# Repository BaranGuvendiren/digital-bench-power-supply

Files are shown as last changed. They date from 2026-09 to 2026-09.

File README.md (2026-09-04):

# digital-bench-power-supply

## Disclaimer & Project Status
I started this project as a 2nd-year Electronics Engineering student to learn power electronics and PCB design in practice.  

While university courses mostly provided hypothetical ideal circuits, this project forced me to confront real-world effects on circuits (e.g., parasitic inductance, ESR, switching noise).

- **No Warranty:** This is **not** a consumer-grade product. While I tried to follow standard engineering practices, it has not undergone any formal testing (such as EMC).

***Current Status:*** *On-going*

***Documentation Notes***:  
- *Currently specified values (voltages, currents, frequencies) are initial design targets and may be optimized later based on future simulations and hardware testing.*
- *Detailed mathematical calculations, circuit schematics and simulation results are currently being formatted and will be documented in their respective sections soon.*

## Features
### Connections & Power
- Powered by a standard laptop adapter (19–20 V, ≥ 65 W) (2.5 mm DC Barrel Jack).
- Includes a USB-C port and SWD pins for PC connection and debugging.
### Protection & Safety
- Reverse polarity protection via P-MOSFET.
- Soft start via P-MOSFET, integrated with a mechanical switch on the gate for system ON/OFF control.
- Temperature-controlled fan.
- NPN-based active current sink at the output rail to maintain LDO stability under zero-load or light-load conditions.
### Output
- Digitally adjustable output (1.2–14 V, up to 2.75 A).
- LDO output with buck controller as a pre-regulator.
- Multi-stage filtering.
- OLED display module.

*Note: A third-party display module is used to prevent the project scope from becoming excessively broad.*

## Design Goals
- Portable design.
- Low-noise output.

## Hardware Architecture Overview
This section provides a simplified blueprint of the system architecture, focusing on the core operating principles and critical design blocks without getting into mathematical formulas or component details.

```mermaid
flowchart LR
  subgraph INPUT_STAGE [Input & Protection]
    IN[Power Adapter] --> PROT[Reverse Prot] --> PI1[Pi-filter]
  end

  subgraph MAIN_RAIL [Main Power Rail]
    PI1 --> BUCK_ADJ[Adjustable Buck]
    BUCK_ADJ --> PI2[Pi-filter] --> SHUNT[Shunt Resistor] --> LDO_ADJ[Adjustable LDO] --> OUT((LOAD))
  end

  subgraph AUX_RAILS [Auxiliary Rails]
    PI1 --> BUCK_5V[5V Buck]
    PI1 --> BUCK_12V[12V Buck]
    BUCK_5V --> PI3[Pi-filter] --> LDO_3V3_D[3V3 Digital]
    BUCK_5V --> PI4[Pi-filter] --> LDO_3V3_A[3V3 Analog]
  end

  subgraph CONTROL [Control & Feedback]
    MCU[MCU]
    AMP[Current Amp]
    DISP[OLED]
    FAN[Fan]
  end

  LDO_3V3_D --> MCU
  LDO_3V3_A --> AMP
  BUCK_5V --> DISP
  BUCK_12V --> FAN

  MCU -.->|V-Set| LDO_ADJ
  MCU -.->|I-Limit| BUCK_ADJ
  MCU -.->|PWM| FAN
  MCU -.->|SPI| DISP
    
  SHUNT -.-> AMP
  AMP -.-> MCU
    
  LDO_ADJ -.->|Pre-reg FB| BUCK_ADJ
```

### Stage 1: Power Input & Input Filtering
* **Input Pre-Filtering:** To prevent beat frequency interference and cross-rail noise coupling, a common CLC Pi-filter is placed immediately after the input.
  
* **Switching Frequency Planning:** To prevent similar interference across rails, operating frequencies are explicitly separated:
    - Laptop Adapter: ~100 kHz
    - Main Buck Regulator: 435 kHz
    - Auxiliary 12 V Buck Regulator: 570 kHz
    - Auxiliary 5 V Buck Regulator: 1 MHz

*Note: Other than common power input, both power rails ("Stage 2A" and "Stage 2B") are independent from each other.*

### Stage 2A: Main Adjustable Power Rail (Buck Converter & LDO)
* **Pre-Regulation:** To achieve stable and low-noise output, an LDO is used. However, since possible high output current may cause an impractical amount of power dissipation, a buck pre-regulator is implemented to maintain a minimal and constant dropout voltage.

* **CC & CV Modes:** While the Constant Current (CC) and Constant Voltage (CV) limits are digitally set by the MCU, relying solely on software poses a reliability risk in high-noise power environments. Therefore, a hardware resistor network restricts the maximum voltage the feedback circuit can receive, preventing both V-set and I-limit signals from exceeding safe operational thresholds.
  
* **Current and Voltage Sensing:** The output current is measured using a shunt resistor paired with a current sense amplifier. The output voltage is sampled via a dedicated voltage divider connected to the LDO output rail. Both analog signals are then processed by the MCU's ADC and displayed on the OLED screen.

### Stage 2B: Auxiliary Power Rails (12 V Buck & 5 V Buck & 3.3 V LDOs)
* **Two-Level Regulation & Noise Isolation:** A 5 V Buck regulator serves as a pre-regulator for the 3.3 V LDOs, while directly powering the fan and the external display. To achieve clean signal processing, separate LDOs are dedicated to the analog and digital rails. This isolation prevents high-frequency digital switching noise from coupling into the sensitive analog rail. Additionally, both LDO lines include a ferrite bead Pi-filter at their inputs to block high-frequency EMI noise that LDOs struggle to suppress.

* **Temperature-Controlled PWM Fan:** To optimize thermal management and minimize both acoustic and electrical noise, the cooling fan operates only when required. The MCU monitors the system temperature and drives an N-MOSFET via PWM to dynamically adjust the fan speed proportional to the device temperature.

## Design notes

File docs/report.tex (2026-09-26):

\documentclass[11pt, a4paper]{article}
\usepackage[top=2.5cm, bottom=2.5cm, left=2cm, right=2cm]{geometry}

\input{variables.tex}

\usepackage[T1]{fontenc}
\usepackage{lmodern}
% \usepackage{helvet}
% \renewcommand{\familydefault}{\sfdefault}
\setlength{\parindent}{0pt}

\usepackage{amsmath, amssymb}
\usepackage{siunitx}
\sisetup{
    scientific-notation = engineering,
    output-decimal-marker = {.},
    drop-zero-decimal = true,
    exponent-to-prefix = true,
    exponent-product = \cdot,
    round-mode = places,
    round-precision = 2,
    per-mode = symbol
}

\usepackage{caption}
\captionsetup[table]{skip=2pt}

\usepackage[colorlinks=true, linkcolor=black, urlcolor=black, citecolor=black]{hyperref}
\usepackage{graphicx}
\graphicspath{{images/}}
\usepackage{fancyhdr}
\pagestyle{fancy}
\fancyhf{}
\fancyhead[L]{\small REVISED \today}
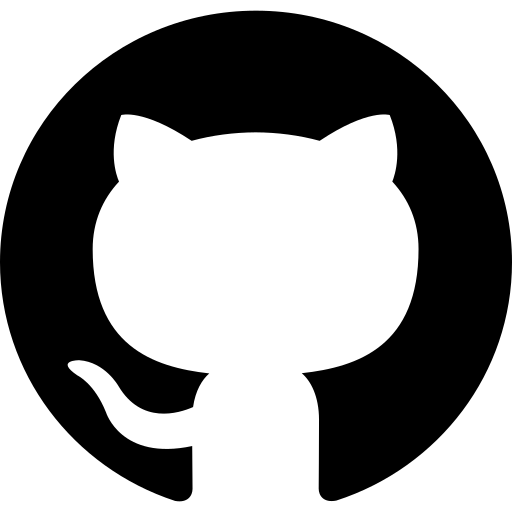
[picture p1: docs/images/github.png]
\fancyhead[R]{\small\raisebox{-0.4ex}{} {\href{https://github.com/BaranGuvendiren/digital-bench-power-supply}{\texttt{GitHub Repository}}}}
\fancyfoot[C]{\thepage}

\usepackage{tabularx}
\usepackage{multirow}
\usepackage[table]{xcolor}
\renewcommand{\arraystretch}{1.4}

\usepackage[most]{tcolorbox}
\newtcolorbox{pickedbox}{
  enhanced,
  blanker,
  borderline west={1pt}{0pt}{gray!50},
  left=10pt, top=4pt, bottom=4pt
}

\usepackage{multicol}
\usepackage{tocloft}
\renewcommand{\cftsecfont}{\small\bfseries\sffamily}
\renewcommand{\cftsecpagefont}{\small\sffamily\color{blue}}
\renewcommand{\cftsubsecfont}{\small\sffamily}
\renewcommand{\cftsubsecpagefont}{\small\sffamily\color{blue}}
\renewcommand{\contentsname}{}
\renewcommand{\cftdotsep}{0.2}
\renewcommand{\cftsecleader}{\cftdotfill{\cftdotsep}}

\setlength{\cftbeforesecskip}{2pt}
\setlength{\cftbeforesubsecskip}{0pt}
\begin{document}

% Title Page
\begin{titlepage}
    \centering
    \vspace*{1.5cm}
    {\scshape\Large Hardware Design \& Verification Report \par}
    \vspace{2.5cm}
    
    {\huge\bfseries Digital Bench Power Supply \par}
    \vspace{0.4cm}
    
    {\Large\itshape Design Calculations, Circuit Simulations \& Hardware Verification \par}
    \rule{\textwidth}{1.2pt}
    
    \vspace{2.5cm}
    
    {\large\bfseries Baran Güvendiren \par}
    \vspace{0.2cm}
    {\small Electronics Engineering Student \par}

    \vfill
    \begin{minipage}{0.85\textwidth}
        \centering
        \small\itshape
        This document contains the complete theoretical calculations, simulation models, component selection justification and hardware verifications for the project.
    \end{minipage}
\end{titlepage}
\clearpage

% Table of Contents
\hypersetup{linkcolor=blue, linktoc=page}

{\centering\Large\bfseries\sffamily Table of Contents \par}
\vspace{0.25cm}

\begin{multicols}{2}
  \setcounter{tocdepth}{2}
  \tableofcontents
  \thispagestyle{fancy}
\end{multicols}
\rule{\textwidth}{0.4pt}

\hypersetup{linkcolor=black}
\clearpage

\section{Calculations \& Component Selection}
\subsection{Overview}
This section contains the theoretical calculations and engineering decisions used to determine the component values for each stage of the power supply. \\[0.5em]
The datasheet files containing manufacturer specifications and references used in these calculations are located in the \small\href{https://github.com/BaranGuvendiren/digital-bench-power-supply/tree/main/docs/datasheets}{\texttt{docs/datasheet/}} directory of the project repository. \\[1em]
{\small\itshape Note: Some calculations are based on idealized formulas with sufficient design margin to ensure system stability and flexibility in component selection. \par}

\normalsize
\subsection{Naming Convention \& Notations}
To maintain mathematical clarity across multiple stages, variables are named using the following conventions:
\begin{table}[h]
\centering
\caption{Naming Convention}
\label{tab:convention}
\small
\begin{tabularx}{\textwidth}{|l|>{\raggedright\arraybackslash}X|l|}
\hline
\rowcolor{gray!20} 
\textbf{Notation Format} & \textbf{Description}               & \textbf{Example} \\ \hline
No Parentheses           & Global board-level variable        & $\mathrm{V_{OUT}}$ (Board output voltage) \\ \hline
With Parentheses         & Component specific to a certain IC & $\mathrm{V_{OUT(U1)}}$ (Output voltage specific to U1 - LM25117) \\ \hline
\end{tabularx}
\end{table}

{\small\itshape Note: The number inside the parentheses indicates which integrated circuit (IC) the variable belongs to. \par}

\begin{table}[h]
\centering
\caption{IC Reference Table}
\label{tab:notations}
\small
\begin{tabularx}{\textwidth}{|c|c|>{\raggedright\arraybackslash}X|}
\hline
\rowcolor{gray!20} 
\textbf{IC Number} & \textbf{Component Name} & \textbf{Description} \\ \hline
1                  & LM25117                 & Main Buck Pre-Regulator \\ \hline
2                  & MIC29302                & Main LDO \\ \hline
4                  & TPS54331                & Auxiliary 5 V Buck Regulator \\ \hline
6                  & TPS54332                & Auxiliary 12 V Buck Regulator \\ \hline
\end{tabularx}
\end{table}

\subsection{LM25117 - U1}
\subsubsection{Timer Resistor \texorpdfstring{$\mathrm{R_{T(U1)}}$}{RT(U1)}}
The switching frequency of the main buck regulator was set to \qty{\fswA}{\hertz} via the $\mathrm{R_{T(U1)}}$ pin resistor; 
this enables sufficient separation from the adapter's lower switching frequency ($\approx \qty{100e3}{\hertz}$) to minimize beat frequency noise, while preventing excessive switching losses at higher frequencies.
\begin{align}
\mathrm{R_{T(U1)}} &= \frac{\num{5.2e9}}{\mathrm{f_{SW(U1)}}} - 949 \nonumber \\[0.5em]
                   &= \frac{\num{5.2e9}}{\num{\fswA}} - 949 \approx \qty{\CalcRtA}{\ohm}
\end{align}
\begin{pickedbox}
\small\textbf{Picked Value(s):}\\[0.5em]
$\diamond\quad \mathrm{R_{T(U1)}} = \qty{\RtA}{\ohm}$
\end{pickedbox}

\subsubsection{Output Inductor \texorpdfstring{$\mathrm{L_{O(U1)}}$}{LO(U1)}}
The output inductance was calculated using a nominal mid-range voltage of $\mathrm{V_{OUT(TYP)}} = \qty{\VoutTyp}{\volt}$ to achieve a balanced ripple current trade-off over the full output voltage range. 
In addition, maximum inductor ripple ($\mathrm{I_{PP(U1)}}$) current was selected as \qty{20}{\percent} of the full load current.
\begin{align}
\mathrm{L_{O(U1)}} &= \frac{\mathrm{V_{OUT(TYP)}}}{\mathrm{I_{PP(U1)}} \cdot \mathrm{f_{SW(U1)}}} \cdot \left(1 - \frac{\mathrm{V_{OUT(TYP)}}}{\mathrm{V_{IN}}}\right) \nonumber  \\[0.5em]
                   &= \frac{\VoutTyp}{\IppA \cdot \num{\fswA}} \cdot \left(1 - \frac{\VoutTyp}{\Vin}\right) \approx \qty{\CalcLoA}{\henry}
\end{align}
\begin{pickedbox}
\small\textbf{Picked Value(s):}\\[0.5em]
$\diamond\quad \mathrm{L_{O(U1)}} = \qty{\LoA}{\henry}$
\end{pickedbox}

\subsubsection{Current Sense Resistor \texorpdfstring{$\mathrm{R_{CS(U1)}}$}{RCS(U1)}}
Maximum output current capability ($\mathrm{I_{OUT(MAX)}}$) was selected as \qty{150}{\percent} of the full load current to account for tolerances. \\[1em]
{\small\itshape Note: Since the LM25117 uses an emulated current ramp, it reads the valley current just before the high-side switch turns on. This means the controller is unaffected by the large leading-edge switching spikes. 
Therefore, a current sense filter was not used in this design to avoid propagation delay on current sensing. \par}
\begin{align}
\mathrm{R_{CS(U1)}}  &= \frac{\mathrm{V_{CS(TH)}}}{\mathrm{I_{OUT(MAX)}} + \dfrac{\mathrm{V_{OUT(TYP)}} \cdot \mathrm{K}}{\mathrm{f_{SW(U1)}} \cdot \mathrm{L_{O(U1)}}} - \dfrac{\mathrm{I_{PP(U1)}}}{2}} \nonumber \\[0.5em]
                     &= \frac{0.12}{\num{\IoutMax} + \dfrac{\num{\VoutTyp} \cdot 1}{\num{\fswA} \cdot \num{\LoA}} - \dfrac{\num{\IppA}}{2}} \approx \qty{\CalcRcsA}{\ohm}\\[1.5em]
\mathrm{P_{RCS(U1)}} &= \left(1 - \frac{\mathrm{V_{OUT(MIN)(U1)}}}{\mathrm{V_{IN}}}\right) \cdot \mathrm{I_{OUT}}^2 \cdot \mathrm{R_{CS(U1)}} \nonumber \\[0.5em]
                     &= \left(1 - \frac{\num{\VoutMin}}{\num{\Vin}}\right) \cdot \num{\Iout}^2 \cdot \num{\RcsA} \approx \qty{\PrcsA}{\watt}
\end{align}
\begin{pickedbox}
\small\textbf{Picked Value(s):}\\[0.5em]
$\diamond\quad \mathrm{R_{CS(U1)}} = \qty{\RcsA}{\ohm}$ \\[0.25em]
$\diamond\quad \mathrm{P_{RCS(U1)}} = \text{[TBD]}$  % \qty{\Prcs}{\watt}
\end{pickedbox}

\subsubsection{Ramp Resistor and Capacitor \texorpdfstring{$\mathrm{R_{RAMP(U1)}}$ and $\mathrm{C_{RAMP(U1)}}$}{CRAMP(U1)}}
Current sense amplifier gain ($\mathrm{A_{RAMP}}$) and K factor are both defined in the datasheet. K factor was set to 1 to prevent sub-harmonic oscillations and ensure one-cycle damping, as recommended in the datasheet. \\[1em]
{\small\itshape Note: The value of $\mathrm{C_{RAMP(U1)}}$ was set to the standard capacitor value of 1 nF. \par}
\begin{align}
\mathrm{R_{RAMP(U1)}} &= \frac{\mathrm{L_{O(U1)}}}{\mathrm{K} \cdot \mathrm{C_{RAMP(U1)}} \cdot \mathrm{R_{CS(U1)}} \cdot \mathrm{A_{RAMP}}} \nonumber \\[0.5em]
                      &= \frac{\num{\LoA}}{1 \cdot \num{\CrampA} \cdot \num{\RcsA} \cdot 10} = \qty{\CalcRrampA}{\ohm}
\end{align}
\begin{pickedbox}
\small\textbf{Picked Value(s):}\\[0.5em]
$\diamond\quad \mathrm{R_{RAMP(U1)}} = \qty{\RrampA}{\ohm}$ \\[0.25em]
$\diamond\quad \mathrm{C_{RAMP(U1)}} = \qty{\CrampA}{\farad}$
\end{pickedbox}

\subsubsection{Output Shunt Resistor \texorpdfstring{$\mathrm{R_S}$}{RS}}
The output current was measured by converting the load current ($\mathrm{I_{OUT(U1)}}$) into an analog voltage signal via a dedicated shunt resistor and a current sense amplifier. The resulting analog signal was then digitized by the MCU's ADC. 
Since the LDO's input current is approximately equal to its output current, the shunt resistor was placed before the feedback node at the LDO input to prevent the voltage drop across the shunt resistor from affecting the regulated output voltage. \\[0.5em]
As low power consumption was not a primary concern for this project, the amplifier gain ($\mathrm{A_S}$) was set to \qty{50}{\times} to minimize the amplification of measurement errors. 
In addition, the reference voltage ($\mathrm{V_{S(REF)}}$) was limited to \qty{3}{\volt}, providing \qty{0.3}{\volt} headroom below the MCU supply voltage to reduce the impact of possible control errors. \\[1em]
{\small\itshape Note: $R_{CS(U1)}$ was used to measure the inductor valley current for LM25117's emulated current-mode control, while $R_S$ was used to calculate the output current for monitoring and setting CC-mode current limit. \par}
\begin{align}
\mathrm{R_S}    &= \frac{\mathrm{V_{S(REF)}} / \mathrm{A_S}}{\mathrm{I_{OUT}}} \nonumber \\[0.5em] 
                &= \frac{\TargVsRef / \As}{\Iout} \approx \qty{\CalcRs}{\ohm} \\[1.5em]
\mathrm{P_{RS}} &= \mathrm{I_{OUT}}^2 \cdot \mathrm{R_S} \nonumber \\[0.5em]
                &= \num{\Iout}^2 \cdot \num{\Rs} \approx \qty{\CalcPrs}{\watt}
\end{align}
\begin{pickedbox}
\small\textbf{Picked Value(s):}\\[0.5em]
$\diamond\quad \mathrm{R_S} = \qty{\Rs}{\ohm}$ \\[0.25em]
$\diamond\quad \mathrm{P_{RS}} = \text{[TBD]}$  % \qty{\Prs}{\watt}
\end{pickedbox}
\end{document}

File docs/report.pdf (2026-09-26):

Hardware Design & Verification Report

# Digital Bench Power Supply

### Design Calculations, Circuit Simulations & Hardware Verification

Baran Güvendiren

Electronics Engineering Student

This document contains the complete theoretical calculations, simulation models, component selection justification and hardware verifications for the project.

REVISED September 26, 2026 | GitHub Repository (https://github.com/BaranGuvendiren/digital-bench-power-supply)

### Table of Contents

### 1 Calculations & Component Selection

### 1.1 Overview

This section contains the theoretical calculations and engineering decisions used to determine the component values for each stage of the power supply.
The datasheet files containing manufacturer specifications and references used in these calculations are located in the docs/datasheet/ (https://github.com/BaranGuvendiren/digital-bench-power-supply/tree/main/docs/datasheets) directory of the project repository.

Note: Some calculations are based on idealized formulas with sufficient design margin to ensure system stability and flexibility in component selection.

### 1.2 Naming Convention & Notations

To maintain mathematical clarity across multiple stages, variables are named using the following conventions:

Table 1: Naming Convention

Notation Format | Description | Example
No Parentheses | Global board-level variable | VOUT (Board output voltage)
With Parentheses | Component specific to a certain IC | VOUT(U1) (Output voltage specific to U1 - LM25117)

Note: The number inside the parentheses indicates which integrated circuit (IC) the variable belongs to.

Table 2: IC Reference Table

IC Number | Component Name | Description
1 | LM25117 | Main Buck Pre-Regulator
2 | MIC29302 | Main LDO
4 | TPS54331 | Auxiliary 5 V Buck Regulator
6 | TPS54332 | Auxiliary 12 V Buck Regulator

### 1.3 LM25117 - U1

### 1.3.1 Timer Resistor RT(U1)

The switching frequency of the main buck regulator was set to 435 kHz via the RT(U1) pin resistor; this enables sufficient separation from the adapter’s lower switching frequency (≈ 100 kHz) to minimize beat frequency noise, while preventing excessive switching losses at higher frequencies.

RT(U1) =

5.20 · 10⁹

fSW(U1)

− 949

=

5.20 · 10⁹
435 · 10³
− 949 ≈ 11.01 kΩ | (1)

Picked Value(s):

⋄ RT(U1) = 11 kΩ

### 1.3.2 Output Inductor LO(U1)

The output inductance was calculated using a nominal mid-range voltage of VOUT(TYP) = 8 V to achieve a balanced ripple current trade-off over the full output voltage range. In addition, maximum inductor ripple (IPP(U1)) current was selected as 20 % of the full load current.

LO(U1) =

VOUT(TYP)

IPP(U1) · fSW(U1)

·

1 −

VOUT(TYP)

VIN

=

8.0
0.55 · 435 · 10³

·

1 −

8.0
20.0
≈ 20.06 µH | (2)

Picked Value(s):

⋄ LO(U1) = 20 µH

### 1.3.3 Current Sense Resistor RCS(U1)

Maximum output current capability (IOUT(MAX)) was selected as 150 % of the full load current to account for tolerances.

Note: Since the LM25117 uses an emulated current ramp, it reads the valley current just before the high-side switch turns on. This means the controller is unaffected by the large leading-edge switching spikes. Therefore, a current sense filter was not used in this design to avoid propagation delay on current sensing.

RCS(U1) =

VCS(TH)

IOUT(MAX) +

VOUT(TYP) · K

fSW(U1) · LO(U1)

−

IPP(U1)
2

=

0.12

4.13 +

8 · 1
435 · 10³ · 20 · 10⁻⁶

−

550 · 10⁻³
2
≈ 25.16 mΩ | (3)

PRCS(U1) =

1 −

VOUT(MIN)(U1)

VIN

- IOUT

2
- RCS(U1)

=

1 −

1.25
20
- 2.75²
- 25 · 10⁻³ ≈ 177.59 mW | (4)

Picked Value(s):

⋄ RCS(U1) = 25 mΩ
⋄ PRCS(U1) = [TBD]

### 1.3.4 Ramp Resistor and Capacitor RRAMP(U1) and CRAMP(U1)

Current sense amplifier gain (ARAMP) and K factor are both defined in the datasheet. K factor was set to 1 to prevent sub-harmonic oscillations and ensure one-cycle damping, as recommended in the datasheet.

Note: The value of CRAMP(U1) was set to the standard capacitor value of 1 nF.

RRAMP(U1) =

LO(U1)

K · CRAMP(U1) · RCS(U1) · ARAMP

=

20 · 10⁻⁶
1 · 1 · 10⁻⁹ · 25 · 10⁻³ · 10
= 80 kΩ | (5)

Picked Value(s):

⋄ RRAMP(U1) = 80 kΩ
⋄ CRAMP(U1) = 1 nF

### 1.3.5 Output Shunt Resistor RS

The output current was measured by converting the load current (IOUT(U1)) into an analog voltage signal via a dedicated shunt resistor and a current sense amplifier. The resulting analog signal was then digitized by the MCU’s ADC. Since the LDO’s input current is approximately equal to its output current, the shunt resistor was placed before the feedback node at the LDO input to prevent the voltage drop across the shunt resistor from affecting the regulated output voltage.
As low power consumption was not a primary concern for this project, the amplifier gain (AS) was set to 50 × to minimize the amplification of measurement errors. In addition, the reference voltage (VS(REF)) was limited to 3 V, providing 300 mV headroom below the MCU supply voltage to reduce the impact of possible control errors.

Note: RCS(U1) was used to measure the inductor valley current for LM25117’s emulated current-mode control, while RS was used to calculate the output current for monitoring and setting CC-mode current limit.

RS =

VS(REF)/AS

IOUT

=

3.0/50
2.75
≈ 21.82 mΩ | (6)

PRS = IOUT

2
- RS

= 2.75²

- 22 · 10⁻³ ≈ 166.38 mW | (7)

Picked Value(s):

⋄ RS = 22 mΩ
⋄ PRS = [TBD]

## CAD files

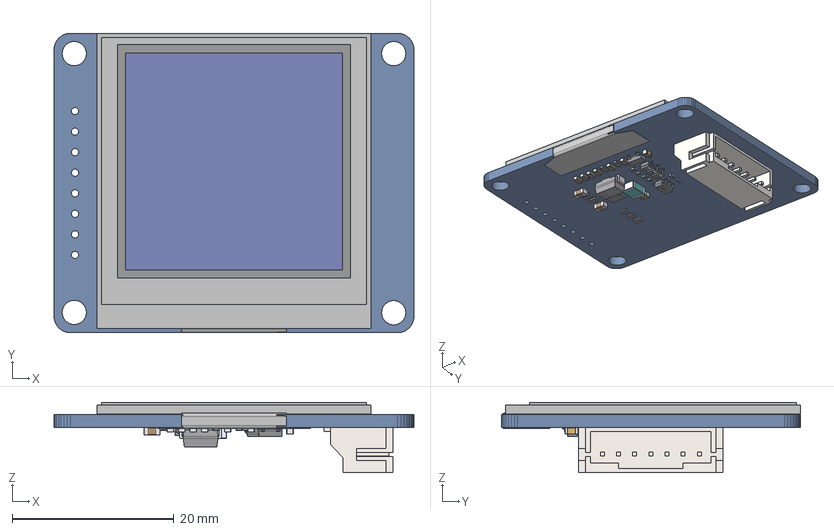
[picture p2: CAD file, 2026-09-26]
enclosure/3d-models/OLED-module.stp
44.5 x 37.0 x 8.70 mm
BOARD
RESC1608_0603_ x 7
SW3DPS-3-LEAD_SOT23-3
USER_LIBRARY-TSOT-23-6_S6_
SW3DPS-DO-214AC_SMA
CAPC2012_0805_ x 2
CAPC1608_0603_ x 6
INDC3225_1210_
SOD323 x 3
5_1_2_A x 7
_7_AF0 x 7
SOT23-5AND6__100 x 6
SOT23-6-7933_AF0
3_1_2_A x 2
1_5INCH-128X128-QLED
HP2_0-7PIN-SMT

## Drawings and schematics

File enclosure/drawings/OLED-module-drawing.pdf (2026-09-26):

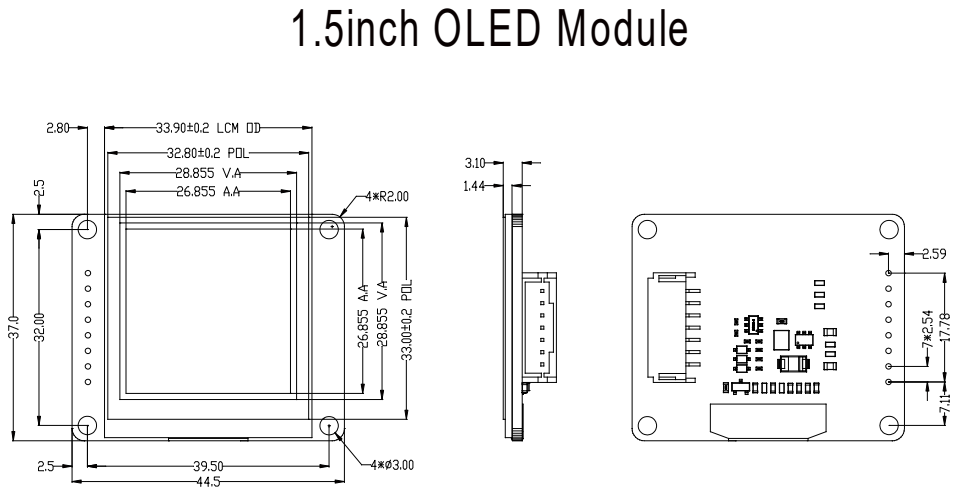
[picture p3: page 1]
1.5inch OLED Module

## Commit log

2026-07-02 docs: update stage 1 in design calculations
2026-07-03 docs: add stage 2A to design calculations
2026-07-04 docs: add hardware architecture flowchart to README
2026-07-04 docs: update stage 2A in design calculations
2026-07-07 docs: update design calculations
    Add new pin calculations and correct regulator efficiency,
    - Update LM25117 parameters to maintain mathematical consistency.
    - Adjust operating limits and voltage calculations accordingly.
2026-07-11 docs: add output shunt resistor to design calculations
2026-09-04 docs: update hardware architecture in README
    Add 12 V rail for fan power
2026-09-26 docs: migrate design calculations from markdown to latex with python automation
    [OLED-module.stp]
